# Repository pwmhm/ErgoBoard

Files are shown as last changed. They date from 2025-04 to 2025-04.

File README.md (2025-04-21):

# Ergonomic Board v1.0

(6x5) sized dactyl-based split ergonomic keyboard generated from [Cosmos Keyboard Generator](https://ryanis.cool/cosmos/). This is a hardwired build so there is no pcb schematic available.

# Features
- Trackball as a mouse (Additionally used as scrolling media)
- Configurable joystick (Currently used as scrolling media)
- 3x3 and 1x5 customizable thumb cluster on left and right side respectively
- VIAL supported

# Installation

## Default Keymap
- make sure qmk is installed (see qmk page on guide)
- for default keymap: copy ergoboard directory to the keyboards section of the qmk parent directory
- run `qmk flash -kb ergoboard -km default -bl avrdude-split-right` (depending on the side change right to left) and put your left/right microcontroller in bootloader mode

## VIAL
- make sure qmk is installed
- clone vial-qmk repository and go inside it
- copy ergoboard into its keyboards/ section
- run `make ergoboard:vial`. If everything is ok there will be a resulting hex file called `ergoboard_vial.hex`
- run `qmk flash -bl avrdude-split-left` (depending on the side change right to left) and put your left/right microcontroller in bootloader mode

# BOM
Below are the bill of materials that were used to make this keyboard. The "Price Single" column shows the normal price of a particular item, and the suceeding column shows how much it was bought for.

| Item | Quantity | Price Single | Price Total (incl. discounts etc.) | 
| --- | --- | --- | --- |
| 3D Printed Case | 2 Pcs | Place-dependant | 10 EUR
| Keycaps (XDA Style) | 74 Pcs | 4.39 EUR for 20pcs | 17.64 EUR |
| MX Switches | 74 Pcs | 2.09 EUR for 10pcs | 15.95 EUR |
| 1N4148 Diode | 74 Pcs | 3.29 EUR for 100pcs | 3.29 EUR | 
| Adafruit Mini Thumbsticks #5628 | 1 Pcs | 6.50 EUR | 11 EUR | 
| PMW3360 Sensor | 1 Pcs | 15.69 EUR | 15.69 EUR | 
| PMW3350 Breakout Board | 1 Pcs | >20 EUR for 5 Pcs | 5.85 EUR |
| 34mm Trackball | 1 Pcs | 8.76 EUR | 8.76 EUR |
| 3 x 6 x 2.5 mm Bearings | 3 Pcs | 4.19 EUR for 10pcs | 4.19 EUR | 
| 3 x 8 Dowel Pins | 3 Pcs | - | 0 EUR (used scraps around the house) | 
| Pro Micro | 2 Pcs | 1.50 EUR for 2 pcs | 3.00 EUR |
| PJ-320A TRRS Jack | 2 Pcs | 1.19 EUR for 10 pcs | 1.19 EUR |
| M3 Screw Inserts | 20 Pcs | 5.99 EUR for a set | 5.99 EUR| 
| M3 Screws | 20 Pcs | 6.99 EUR for a set | 6.99 EUR|
| Jumper Wires | As much as needed | 1.30 EUR for a set | 1.30 EUR
| Male Pin Headers | 25 pcs | 1.20 EUR for a set | 1.20 EUR|
| Dupont jumper wires | approx. 40 Pcs | 1.90 EUR for a set | 1.90 EUR|

The Male pin headers and dupont wires are optional, but they do make it easier when installing the mcu and allows you to change pins arbitrarily. Additionally, the trrs connector for the two keyboards are not included.

PMW3360 Breakout costs quite a lot of money to make, mainly because of the PCBA service. If you are able to do smd soldering, you can save quite some money on this. Also, it is worth noting that i got the price to 5.85 EUR by using their discount coupon for new users.

3D printed case can vary a lot. Retail prices online with this model shows upwards of 40 EUR for it. In my case, i decided to source it locally (aka colleagues) which means only the material cost were accounted for.

Since this is a hardwired build, please also note that this assumes you have good knowledge about soldering and already have soldering tools available.

# Troubleshooting

Common problem with pro-micro mcus is that they are sometimes unrecognizable when connected to a pc. This is the case with micro-usb pro-micro that i used. In this case, please check if connecting the pro-micro to a usb-c port instead of usb-a solves the problem.

# Build Guide
TBD

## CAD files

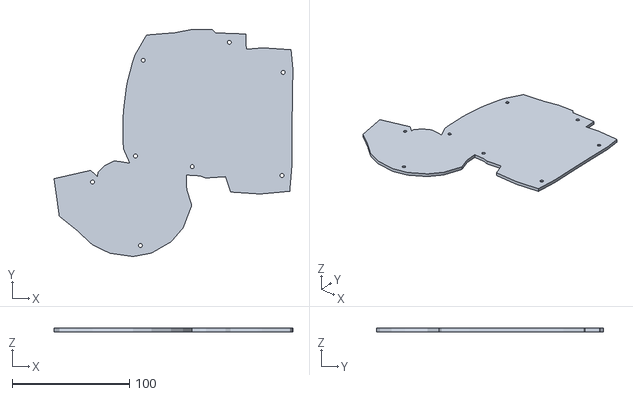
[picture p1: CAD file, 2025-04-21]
model/plate_right.stl
203.9 x 193.8 x 3.00

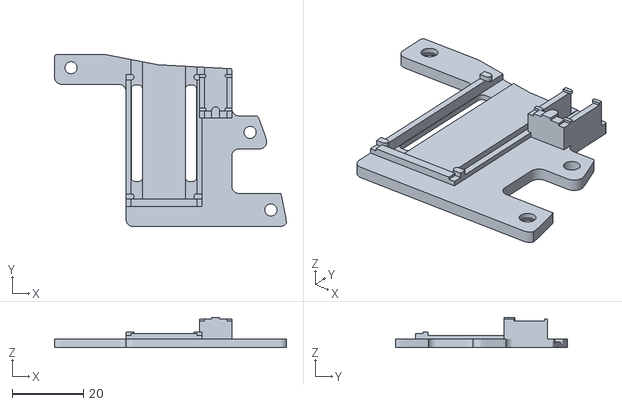
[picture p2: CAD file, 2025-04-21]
model/holder_left.stl
65.1 x 48.3 x 8.50

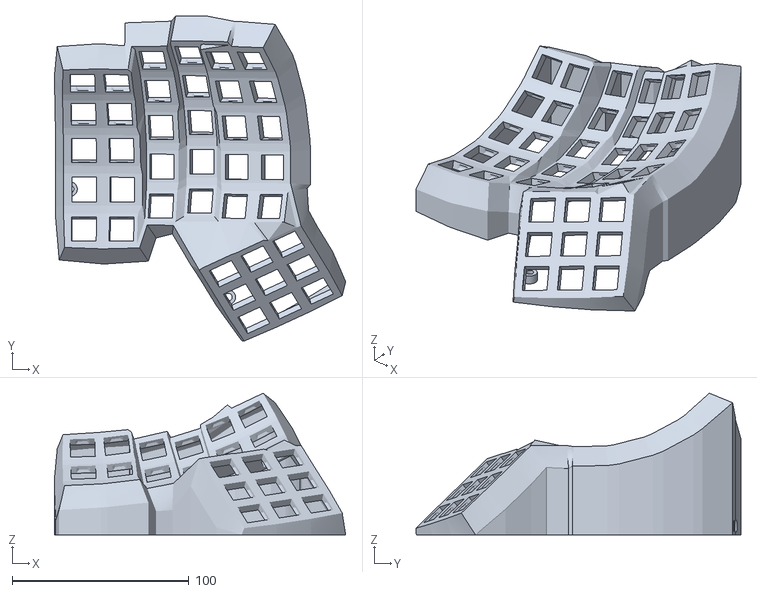
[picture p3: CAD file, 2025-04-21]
model/case_left.stl
164.9 x 184.0 x 80.2

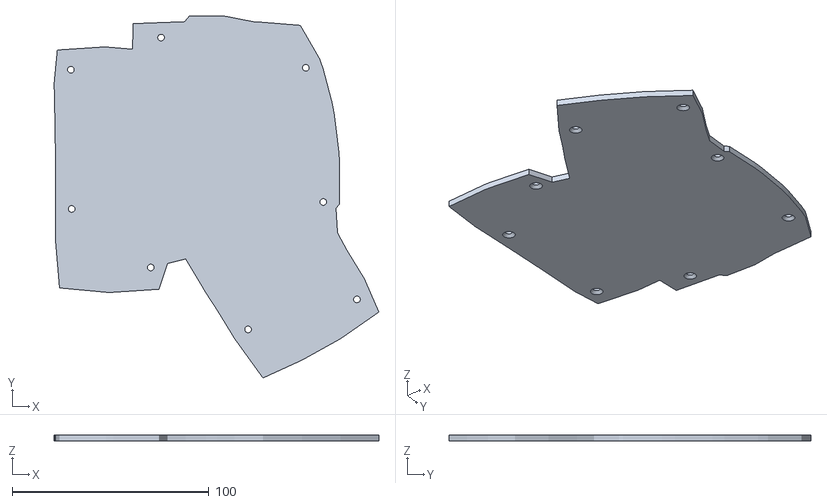
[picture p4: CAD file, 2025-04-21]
model/plate_left.stl
164.9 x 183.8 x 3.00

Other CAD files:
model/holder_right.stl

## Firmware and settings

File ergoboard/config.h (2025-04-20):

/* Copyright 2024 Juho T. (@Squalius-cephalus)
 *
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
 * You should have received a copy of the GNU General Public License
 * along with this program.  If not, see <http://www.gnu.org/licenses/>.
 */

#pragma once

#define SOFT_SERIAL_PIN D2
#define EE_HANDS

#define SPLIT_USB_DETECT
#define SPLIT_USB_TIMEOUT_POLL 10
#define SPLIT_WATCHDOG_ENABLE
#define SPLIT_WATCHDOG_TIMEOUT 3000

#define JOYSTICK_BUTTON_COUNT 1
#define JOYSTICK_AXIS_COUNT 2
#define JOYSTICK_AXIS_RESOLUTION 10

#define SPLIT_POINTING_ENABLE
#define POINTING_DEVICE_RIGHT
#define PMW33XX_CS_PIN B6
#define ROTATIONAL_TRANSFORM_ANGLE 80
#define POINTING_DEVICE_INVERT_Y

#define MATRIX_COL_PINS_RIGHT { D3, D5, F7, F6, F5, F4 }
#define MATRIX_ROW_PINS_RIGHT { D1, D0, D4, C6, D7, E6, NO_PIN }

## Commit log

2025-04-21 add stl files of the keyboard case, plate, and mcu holder.
    [case_left.stl, holder_left.stl, holder_right.stl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]
2025-04-21 add BOM and additional tips

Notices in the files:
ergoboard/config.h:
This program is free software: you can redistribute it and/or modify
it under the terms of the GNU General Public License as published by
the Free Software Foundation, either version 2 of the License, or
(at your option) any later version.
